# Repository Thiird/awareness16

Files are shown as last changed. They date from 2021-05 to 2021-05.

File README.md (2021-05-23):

# Awareness16
Mechanical macropad, used as pathfinder for my first custom mechanical keyboard build.  

**SPECS**  
-16 1U keys in a 4x4 matrix, MX footprint

-USB C, CtoC compatible

-RGB Matrix, 6028 SMD LEDs 

-RGB underglow, SK6812MINI-E SMD LEDs

-ESD protection

-MCU: Atmega 32u4, TQFP44 package

-LED driver: IS31FL3733, eTQFP-48 package

# Renderings

**PCB top**
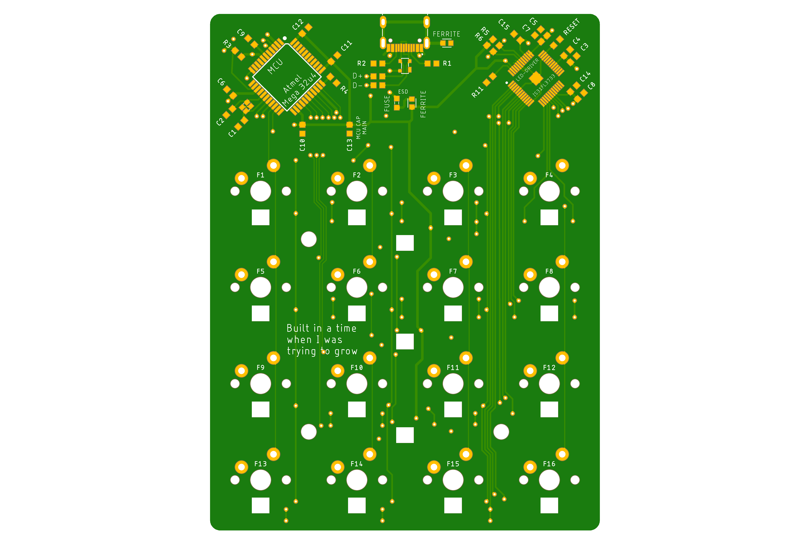
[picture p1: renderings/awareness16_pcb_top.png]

     
**PCB bottom**
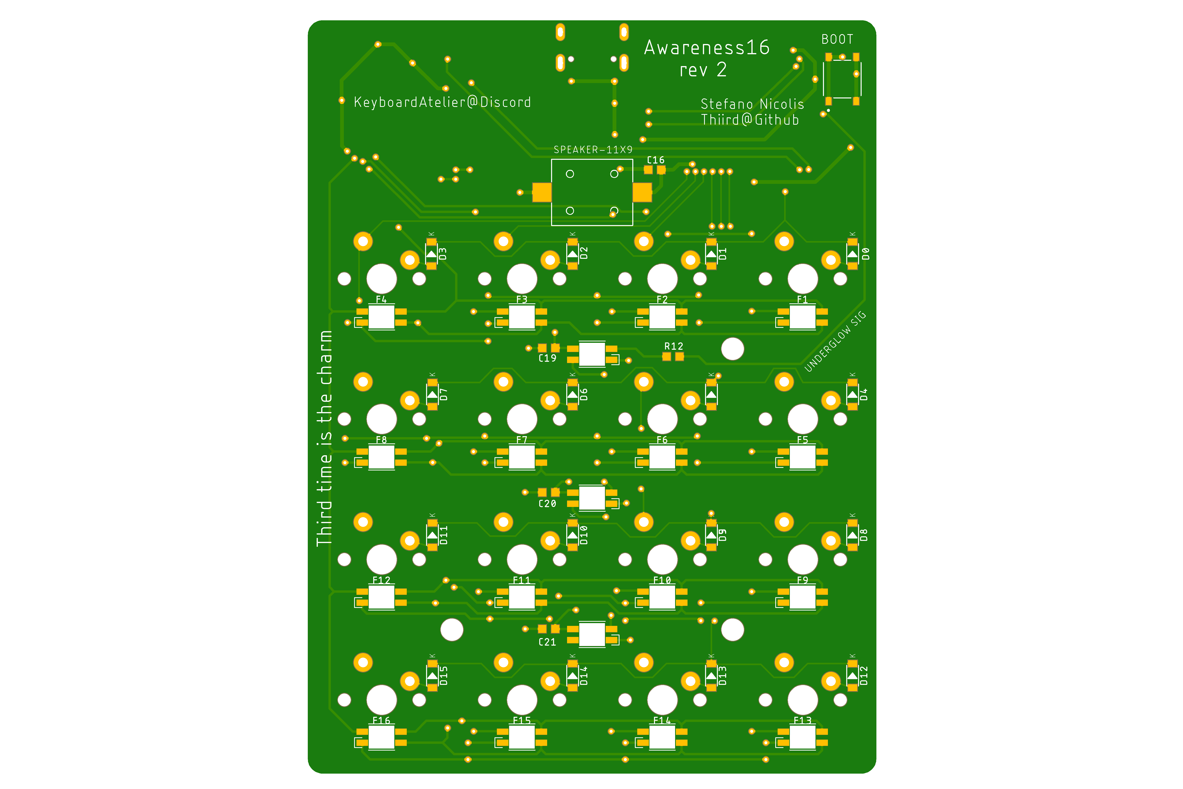
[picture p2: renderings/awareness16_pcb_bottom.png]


# Credits
Without the help of many generous and patient people online I would have never been able to complete
this project.

Special thanks to:
- Hadi for making a pcb guide series: https://www.youtube.com/channel/UCpWGAJr2AU7LPUwVYbBQZRg
- People on the Keyboard Atelier discord
- People on the QMK discord

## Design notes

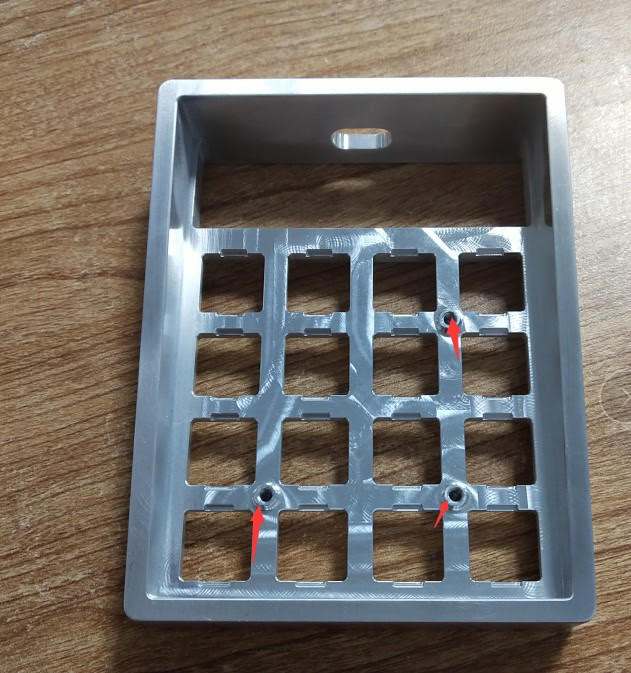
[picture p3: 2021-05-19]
renderings/case_raw.jpg

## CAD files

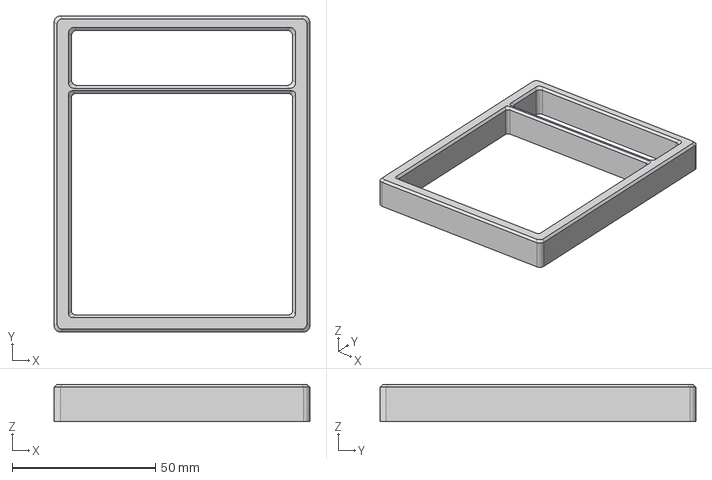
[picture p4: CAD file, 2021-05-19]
topcase.step
89.2 x 110.2 x 13.0 mm

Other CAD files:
autocad files/top_case_full.dwg

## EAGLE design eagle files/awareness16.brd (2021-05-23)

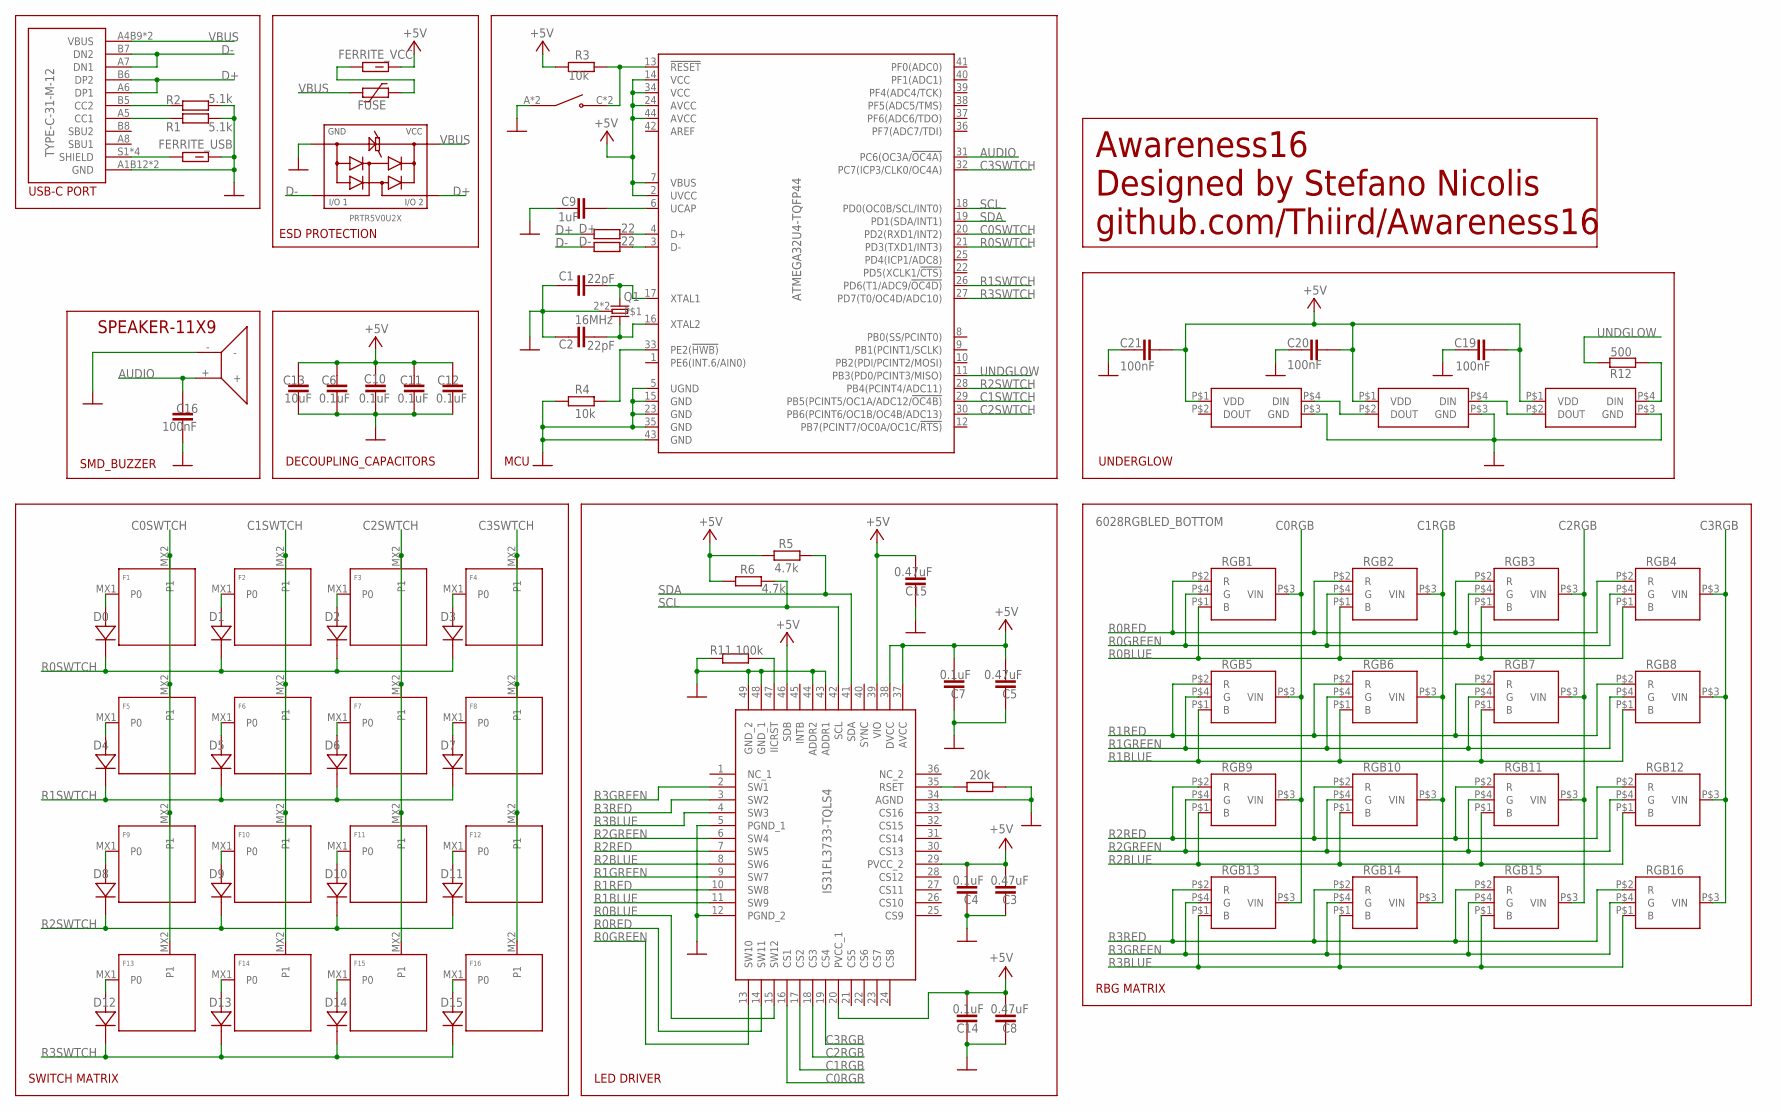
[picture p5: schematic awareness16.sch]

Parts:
C1, C2: 22pF; C0603
C3, C5, C8, C15: 0.47uF; C0603
C4, C6, C7, C10, C11, C12, C14: 0.1uF; C0603
C9: 1uF; C0603
C13: 10uF; C0603
C16, C19, C20, C21: 100nF; C0603
D0, D1, D2, D3, D4, D5, D6, D7, D8, D9, D10, D11, D12, D13, D14, D15: DIODE-SOD-123; SOD-123
D+: 22; R0603
D-: 22; R0603
DRIVER: IS31FL3733-TQLS4; QFP50P900X900X120-49N
F1, F2, F3, F4, F5, F6, F7, F8, F9, F10, F11, F12, F13, F14, F15, F16: KEYSWITCH-PLAIN-MX-1U; MX-1U
FERRITE_USB: FERRITE_BEAD; BEADC1608X95N
FERRITE_VCC: FERRITE_BEAD; BEADC1608X95N
FUSE: 0603L050; 0603L
J1: TYPE-C-31-M-12; HRO_TYPE-C-31-M-12
MCU: ATMEGA32U4-TQFP44; TQFP44-0.8-9.6X9.6MM
Q1: 16MHz; 2.0X1.6_KX-5
R1, R2: 5.1k; R0603
R3, R4: 10k; R0603
R5, R6: 4.7k; R0603
R11: 100k; R0603
R12: 500; R0603
RESET: 20k; R0603
RGB1, RGB2, RGB3, RGB4, RGB5, RGB6, RGB7, RGB8, RGB9, RGB10, RGB11, RGB12, RGB13, RGB14, RGB15, RGB16: 6028RGBLED_BOTTOM
S1: TS-1187A-B-A-B; SW_TS-1187A-B-A-B
SP1: SPEAKER-11X9; AST1109MLTRQ
U$1: PRTR5V0U2X
UGLOW1, UGLOW2, UGLOW3: SK6812MINI-E

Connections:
AUDIO: C16.1, MCU.31 (PC6(OC3A/!OC4A)), SP1.+
C0RGB: DRIVER.16 (CS1), RGB1.P$3 (VIN), RGB5.P$3 (VIN), RGB9.P$3 (VIN), RGB13.P$3 (VIN)
C0SWTCH: F1.MX2 (P1), F5.MX2 (P1), F9.MX2 (P1), F13.MX2 (P1), MCU.20 (PD2(RXD1/INT2))
C1RGB: DRIVER.17 (CS2), RGB2.P$3 (VIN), RGB6.P$3 (VIN), RGB10.P$3 (VIN), RGB14.P$3 (VIN)
C1SWTCH: F2.MX2 (P1), F6.MX2 (P1), F10.MX2 (P1), F14.MX2 (P1), MCU.29 (PB5(PCINT5/OC1A/ADC12/!OC4B))
C2RGB: DRIVER.18 (CS3), RGB3.P$3 (VIN), RGB7.P$3 (VIN), RGB11.P$3 (VIN), RGB15.P$3 (VIN)
C2SWTCH: F3.MX2 (P1), F7.MX2 (P1), F11.MX2 (P1), F15.MX2 (P1), MCU.30 (PB6(PCINT6/OC1B/OC4B/ADC13))
C3RGB: DRIVER.19 (CS4), RGB4.P$3 (VIN), RGB8.P$3 (VIN), RGB12.P$3 (VIN), RGB16.P$3 (VIN)
C3SWTCH: F4.MX2 (P1), F8.MX2 (P1), F12.MX2 (P1), F16.MX2 (P1), MCU.32 (PC7(ICP3/CLK0/OC4A))
D+: D+.1, J1.A6 (DP1), J1.B6 (DP2), U$1.3
D-: D-.1, J1.A7 (DN1), J1.B7 (DN2), U$1.2
GND: C1.1, C2.1, C3.1, C4.1, C5.1, C6.2, C7.1, C8.1, C9.1, C10.2, C11.2, C12.2, C13.2, C14.1, C15.1, C16.2, C19.1, C20.1, C21.1, DRIVER.5 (PGND_1), DRIVER.12 (PGND_2), DRIVER.34 (AGND), DRIVER.43 (ADDR1), DRIVER.44 (ADDR2), DRIVER.48 (GND_1), DRIVER.49 (GND_2), FERRITE_USB.2, J1.A1B12 (GND), J1.B1A12 (GND), MCU.5 (UGND), MCU.15 (GND), MCU.23 (GND), MCU.35 (GND), MCU.43 (GND), Q1.2, Q1.4, R1.1, R2.1, R4.1, R11.1, RESET.2, S1.A (COM), S1.B (COM), SP1.-, U$1.1, UGLOW1.P$3 (GND), UGLOW2.P$3 (GND), UGLOW3.P$3 (GND)
unnamed: D0.A, F1.MX1 (P0)
unnamed: FERRITE_VCC.1, FUSE.1
unnamed: D1.A, F2.MX1 (P0)
unnamed: D2.A, F3.MX1 (P0)
unnamed: C2.2, MCU.16 (XTAL2), Q1.3 (2)
unnamed: D-.2, MCU.3 (D-)
unnamed: R12.1, UGLOW3.P$4 (DIN)
unnamed: MCU.33 (PE2(!HWB)), R4.2
unnamed: D4.A, F5.MX1 (P0)
unnamed: DRIVER.47 (IICRST), R11.2
unnamed: D5.A, F6.MX1 (P0)
unnamed: D6.A, F7.MX1 (P0)
unnamed: D9.A, F10.MX1 (P0)
unnamed: D+.2, MCU.4 (D+)
unnamed: MCU.13 (!RESET), R3.2, S1.C (NO), S1.D (NO)
unnamed: C9.2, MCU.6 (UCAP)
unnamed: C1.2, MCU.17 (XTAL1), Q1.1
unnamed: D10.A, F11.MX1 (P0)
unnamed: FERRITE_USB.1, J1.A5 (CC1), J1.B5 (CC2), J1.S1 (SHIELD), J1.S2 (SHIELD), J1.S3 (SHIELD), J1.S4 (SHIELD), R1.2, R2.2
unnamed: UGLOW1.P$4 (DIN), UGLOW2.P$2 (DOUT)
unnamed: DRIVER.35 (RSET), RESET.1
unnamed: D3.A, F4.MX1 (P0)
unnamed: D7.A, F8.MX1 (P0)
unnamed: D11.A, F12.MX1 (P0)
unnamed: D13.A, F14.MX1 (P0)
unnamed: D14.A, F15.MX1 (P0)
unnamed: D12.A, F13.MX1 (P0)
unnamed: D15.A, F16.MX1 (P0)
unnamed: D8.A, F9.MX1 (P0)
unnamed: UGLOW2.P$4 (DIN), UGLOW3.P$2 (DOUT)
R0BLUE: DRIVER.15 (SW12), RGB1.P$1 (B), RGB2.P$1 (B), RGB3.P$1 (B), RGB4.P$1 (B)
R0GREEN: DRIVER.13 (SW10), RGB1.P$4 (G), RGB2.P$4 (G), RGB3.P$4 (G), RGB4.P$4 (G)
R0RED: DRIVER.14 (SW11), RGB1.P$2 (R), RGB2.P$2 (R), RGB3.P$2 (R), RGB4.P$2 (R)
R0SWTCH: D0.C, D1.C, D2.C, D3.C, MCU.21 (PD3(TXD1/INT3))
R1BLUE: DRIVER.11 (SW9), RGB5.P$1 (B), RGB6.P$1 (B), RGB7.P$1 (B), RGB8.P$1 (B)
R1GREEN: DRIVER.9 (SW7), RGB5.P$4 (G), RGB6.P$4 (G), RGB7.P$4 (G), RGB8.P$4 (G)
R1RED: DRIVER.10 (SW8), RGB5.P$2 (R), RGB6.P$2 (R), RGB7.P$2 (R), RGB8.P$2 (R)
R1SWTCH: D4.C, D5.C, D6.C, D7.C, MCU.26 (PD6(T1/ADC9/!OC4D))
R2BLUE: DRIVER.8 (SW6), RGB9.P$1 (B), RGB10.P$1 (B), RGB11.P$1 (B), RGB12.P$1 (B)
R2GREEN: DRIVER.6 (SW4), RGB9.P$4 (G), RGB10.P$4 (G), RGB11.P$4 (G), RGB12.P$4 (G)
R2RED: DRIVER.7 (SW5), RGB9.P$2 (R), RGB10.P$2 (R), RGB11.P$2 (R), RGB12.P$2 (R)
R2SWTCH: D8.C, D9.C, D10.C, D11.C, MCU.28 (PB4(PCINT4/ADC11))
R3BLUE: DRIVER.4 (SW3), RGB13.P$1 (B), RGB14.P$1 (B), RGB15.P$1 (B), RGB16.P$1 (B)
R3GREEN: DRIVER.2 (SW1), RGB13.P$4 (G), RGB14.P$4 (G), RGB15.P$4 (G), RGB16.P$4 (G)
R3RED: DRIVER.3 (SW2), RGB13.P$2 (R), RGB14.P$2 (R), RGB15.P$2 (R), RGB16.P$2 (R)
R3SWTCH: D12.C, D13.C, D14.C, D15.C, MCU.27 (PD7(T0/OC4D/ADC10))
SCL: DRIVER.42 (SCL), MCU.18 (PD0(OC0B/SCL/INT0)), R6.1
SDA: DRIVER.41 (SDA), MCU.19 (PD1(SDA/INT1)), R5.1
UNDGLOW: MCU.11 (PB3(PD0/PCINT3/MISO)), R12.2
VBUS: FUSE.2, J1.A4B9 (VBUS), J1.B4A9 (VBUS), U$1.4
VCC: C3.2, C4.2, C5.2, C6.1, C7.2, C8.2, C10.1, C11.1, C12.1, C13.1, C14.2, C15.2, C19.2, C20.2, C21.2, DRIVER.20 (PVCC_1), DRIVER.29 (PVCC_2), DRIVER.37 (AVCC), DRIVER.38 (DVCC), DRIVER.39 (VIO), DRIVER.46 (SDB), FERRITE_VCC.2, MCU.2 (UVCC), MCU.7 (VBUS), MCU.14 (VCC), MCU.24 (AVCC), MCU.34 (VCC), MCU.44 (AVCC), R3.1, R5.2, R6.2, UGLOW1.P$1 (VDD), UGLOW2.P$1 (VDD), UGLOW3.P$1 (VDD)

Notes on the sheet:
MCU
UNDERGLOW
SWITCH MATRIX
RBG MATRIX
ESD PROTECTION
DECOUPLING_CAPACITORS
LED DRIVER
SMD_BUZZER
USB-C PORT
Awareness16 Designed by Stefano Nicolis github.com/Thiird/Awareness16

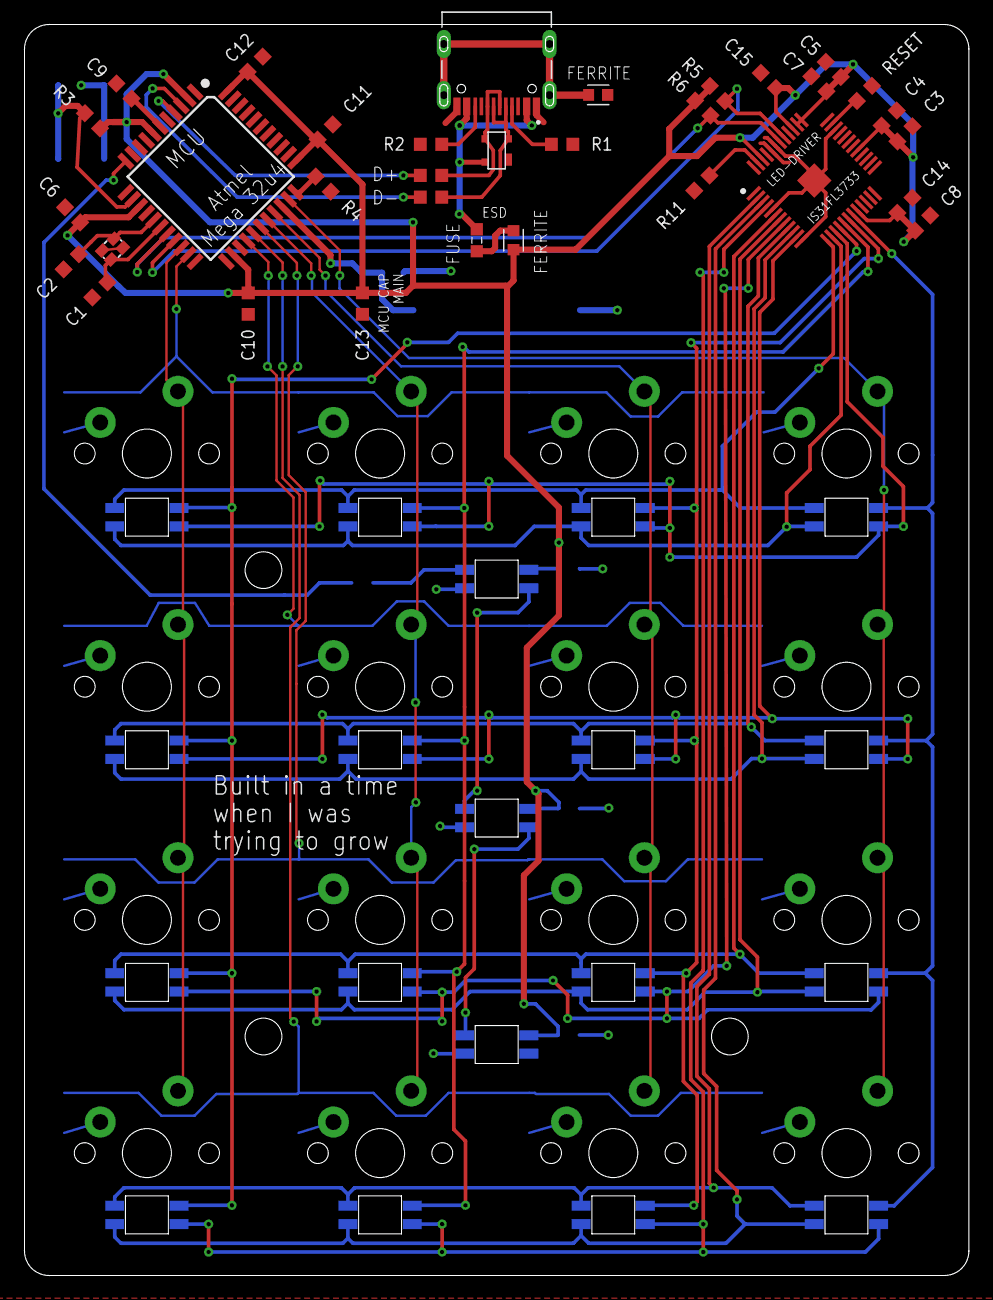
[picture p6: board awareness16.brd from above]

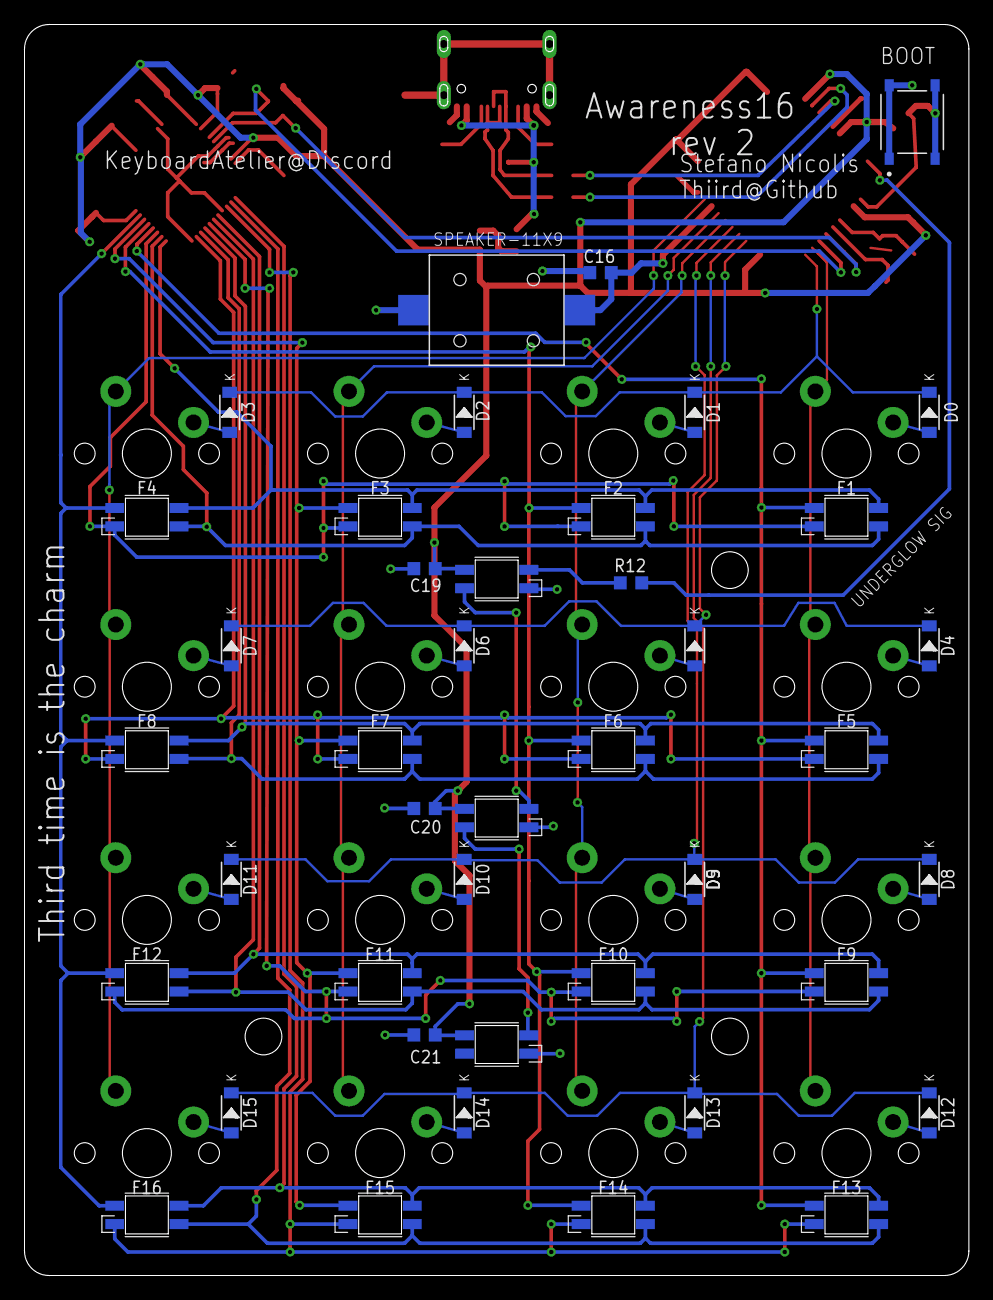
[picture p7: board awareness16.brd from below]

Board: 2 copper layers, 77.2 x 102.2 mm, 91 parts (26 on the bottom side), 63 nets.

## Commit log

2020-10-18 schematic and board files added
    [32u4_macropad.brd, 32u4_macropad.sch, board_atmega.brd]
2020-10-19 Added underglow WS2812B LEDs
    [32u4_macropad.brd, 32u4_macropad.sch, board_atmega.brd]
2020-10-23 New SK6812MINI-E footprint, added ground pin on crystal, fixed misconnections
    [32u4_macropad.brd, 32u4_macropad.sch]
2020-10-24 started board, added rgb matrix
    [32u4_macropad.brd, 32u4_macropad.sch, switch_matrix.dxf]
2020-10-25 ESD protection, dxf board-switch matrix reference, started routing
    [32u4_macropad.brd, 32u4_macropad.sch, board_dimension.dxf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]
2020-10-27 Board layout progress
2020-10-29 ESD Finished, led driver work, board placement work
    [32u4_macropad.brd, 32u4_macropad.sch]
2020-10-30 Led driver finished, usb footprint made unilateral and fixed D+ D- connection, board work
    [32u4_macropad.brd, 32u4_macropad.sch]
2020-10-31 Major board routing, GND net fix
    [32u4_macropad.brd, 32u4_macropad.sch]
2020-11-01 Board USB are work, minor fixes
    [32u4_macropad.brd, 32u4_macropad.sch]
2020-11-01 GND net fixes, drc checks, other fixes
    [32u4_macropad.brd, 32u4_macropad.sch]
2020-11-02 ESD routing fix and finished, usb data line resistors moved after ESD, minor fixes
    [32u4_macropad.brd, 32u4_macropad.sch]
2020-11-07 Routing fixes
    [32u4_macropad.brd, 32u4_macropad.sch]
2020-11-08 Added rendering folder, enlargerd gnd plane, traces width corrected
    [32u4_macropad.brd]
2020-11-10 Small routing fixes, added credits in sch and brd
    [32u4_macropad.brd, 32u4_macropad.sch]
2020-11-11 Led driver connections to leds fixed in sch and brd
    [32u4_macropad.brd, 32u4_macropad.sch]
2020-11-13 brd minor fixes
    [32u4_macropad.brd, 32u4_macropad.sch]
2020-11-16 Enlarged pcb on top for case matching, re routed to accomodate this change
    [32u4_macropad.brd, 32u4_macropad.sch]
2020-11-19 Small board fixes
    [32u4_macropad.brd, 32u4_macropad.sch]
2020-12-24 Fixed xtal caps value and missing C4 name on brd
    [32u4_macropad.brd, 32u4_macropad.sch]
2020-12-29 Component font size, routing adjustments
    [32u4_macropad.brd]
2021-03-14 Rev 1 start
    [32u4_macropad.brd]
2021-03-14 Fixed gnd plane not reaching underglow led #3, routing revision
    [32u4_macropad.brd]
2021-03-15 Backlight led footprint fixed, started rerouting of those and other routing fixes
    [32u4_macropad.brd]
2021-03-16 Rgb matrix leds routing done, underglow leds routing done
    [32u4_macropad.brd, 32u4_macropad.sch]
2021-03-18 REV 1 final commit
    [32u4_macropad.brd, 32u4_macropad.sch]
2021-04-25 Revision 2, added a decent bootloader button on back of board, routing fixes
    [awareness16.brd, awareness16.sch]
2021-05-19 Repo clean up, readme update
    [32u4_macropad.brd, 32u4_macropad.sch, awareness16.brd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]
2021-05-23 Minor board adjustments
    [awareness16.brd]

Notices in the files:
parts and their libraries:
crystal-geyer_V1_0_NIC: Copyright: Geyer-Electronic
